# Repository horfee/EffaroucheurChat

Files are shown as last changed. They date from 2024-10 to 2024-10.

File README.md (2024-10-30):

# Effaroucheur à Chat

This project is a design of a board, based on ESP32, to control ultra sound speaker according to infrared motion sensors.

It is powered by 2 solar panels, with a LDO MP2161GJ-Z to power efficiently the device.

Used components are :
- MP2161GJ-Z
- ESP32 WROOM
- TP4056 as battery charger
- HC-SR501 for motion sensors
- << insert speaker ref here >>
- FT232RL to discuss with ESP32 for flash phase
- UMH3N to enabled RTS/DTR mechanism

Flash firmware will come later.

Current design is this :
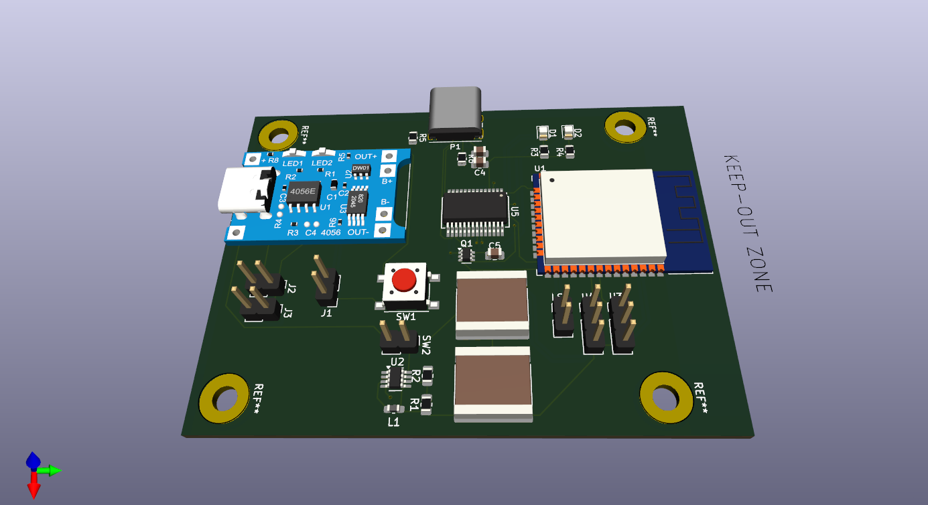
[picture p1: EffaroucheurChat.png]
The actual board


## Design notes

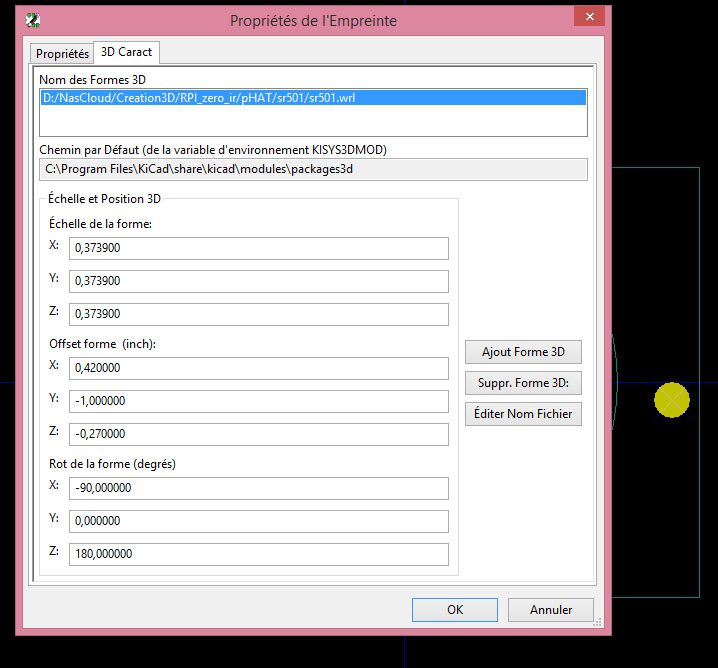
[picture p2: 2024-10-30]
HC-SR501/kidac3D1.jpg

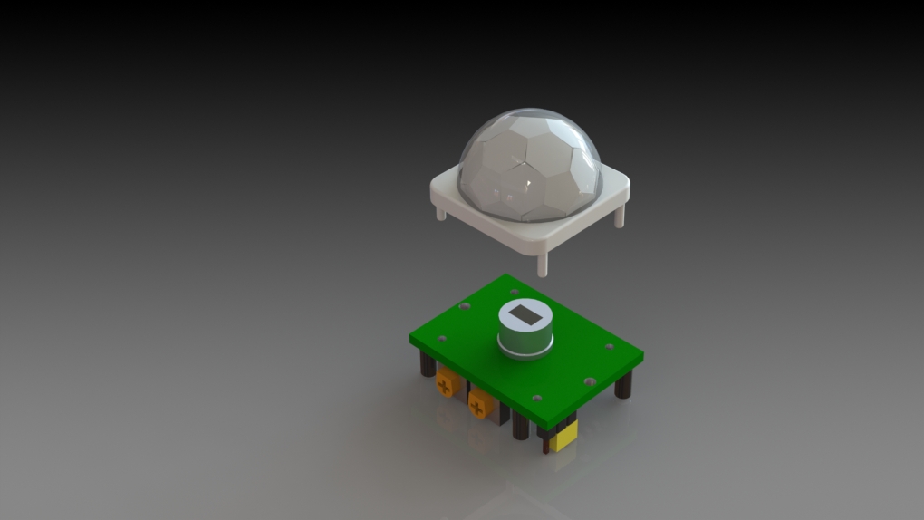
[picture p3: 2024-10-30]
HC-SR501/exploded sensor.JPG

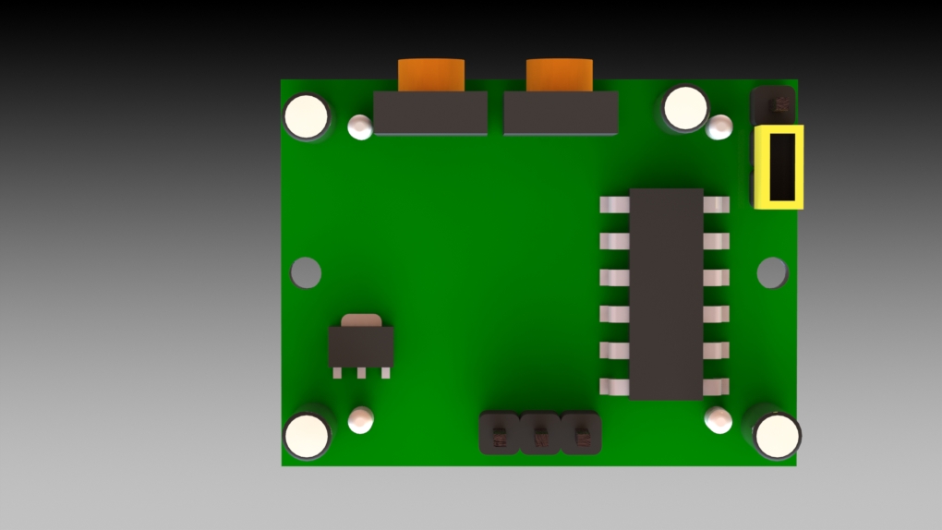
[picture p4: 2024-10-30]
HC-SR501/sensor board.JPG

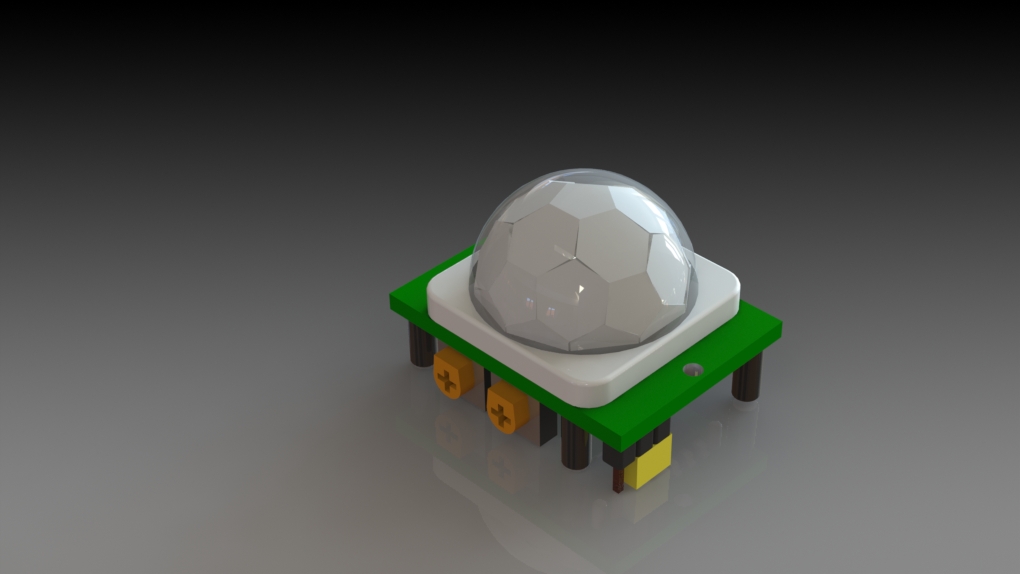
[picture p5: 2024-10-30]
HC-SR501/sensor render.JPG

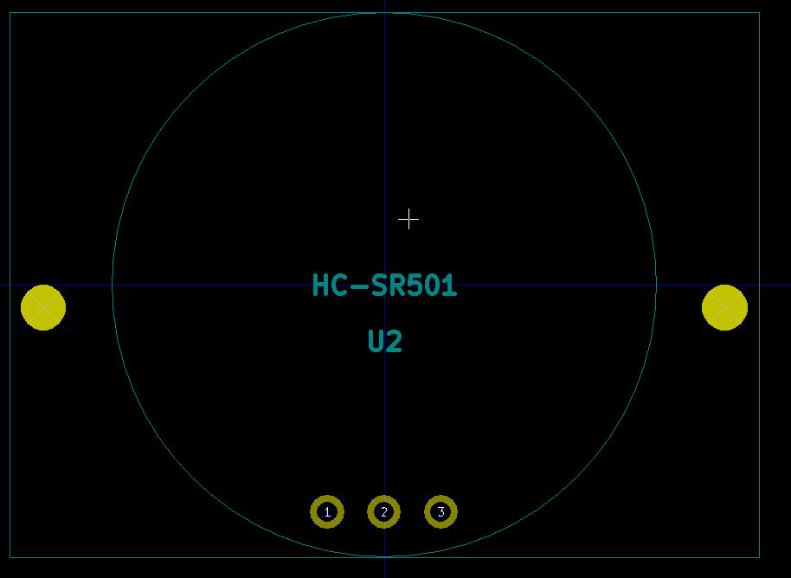
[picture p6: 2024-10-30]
HC-SR501/kidac3D2.jpg

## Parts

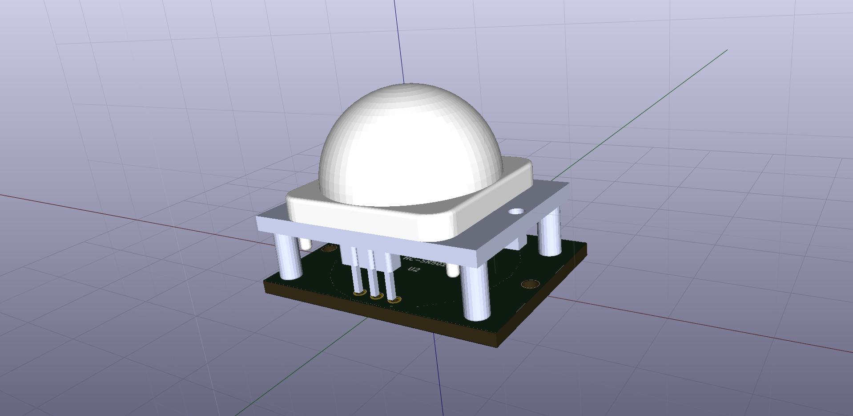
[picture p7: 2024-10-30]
HC-SR501/component.jpg

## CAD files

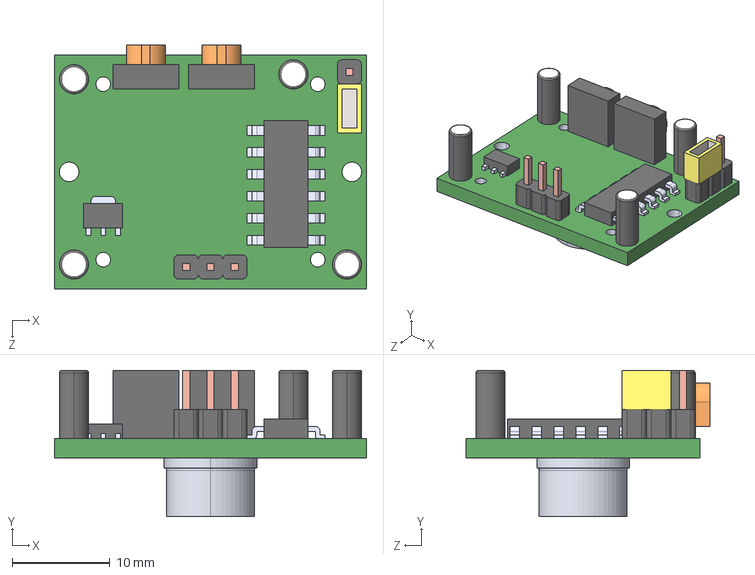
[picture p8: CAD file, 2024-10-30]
HC-SR501/sensor board.STEP
32.0 x 15.0 x 25.0 mm

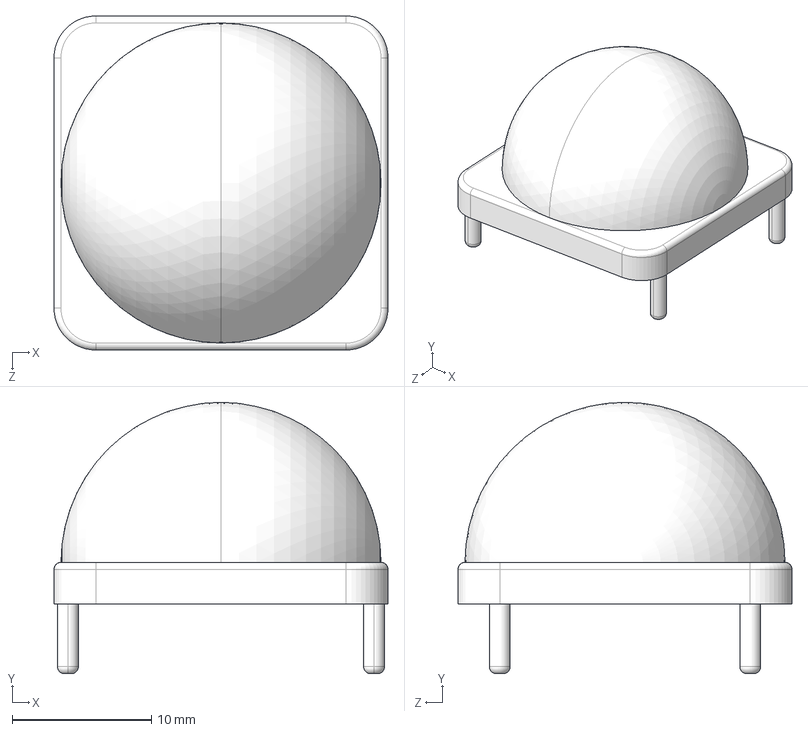
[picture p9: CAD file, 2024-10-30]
HC-SR501/lens.STEP
24.0 x 19.5 x 24.0 mm

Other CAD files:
HC-SR501/sensor.STEP
HC-SR501/lens.SLDPRT
HC-SR501/sensor.SLDASM
HC-SR501/sensor.SLDPRT

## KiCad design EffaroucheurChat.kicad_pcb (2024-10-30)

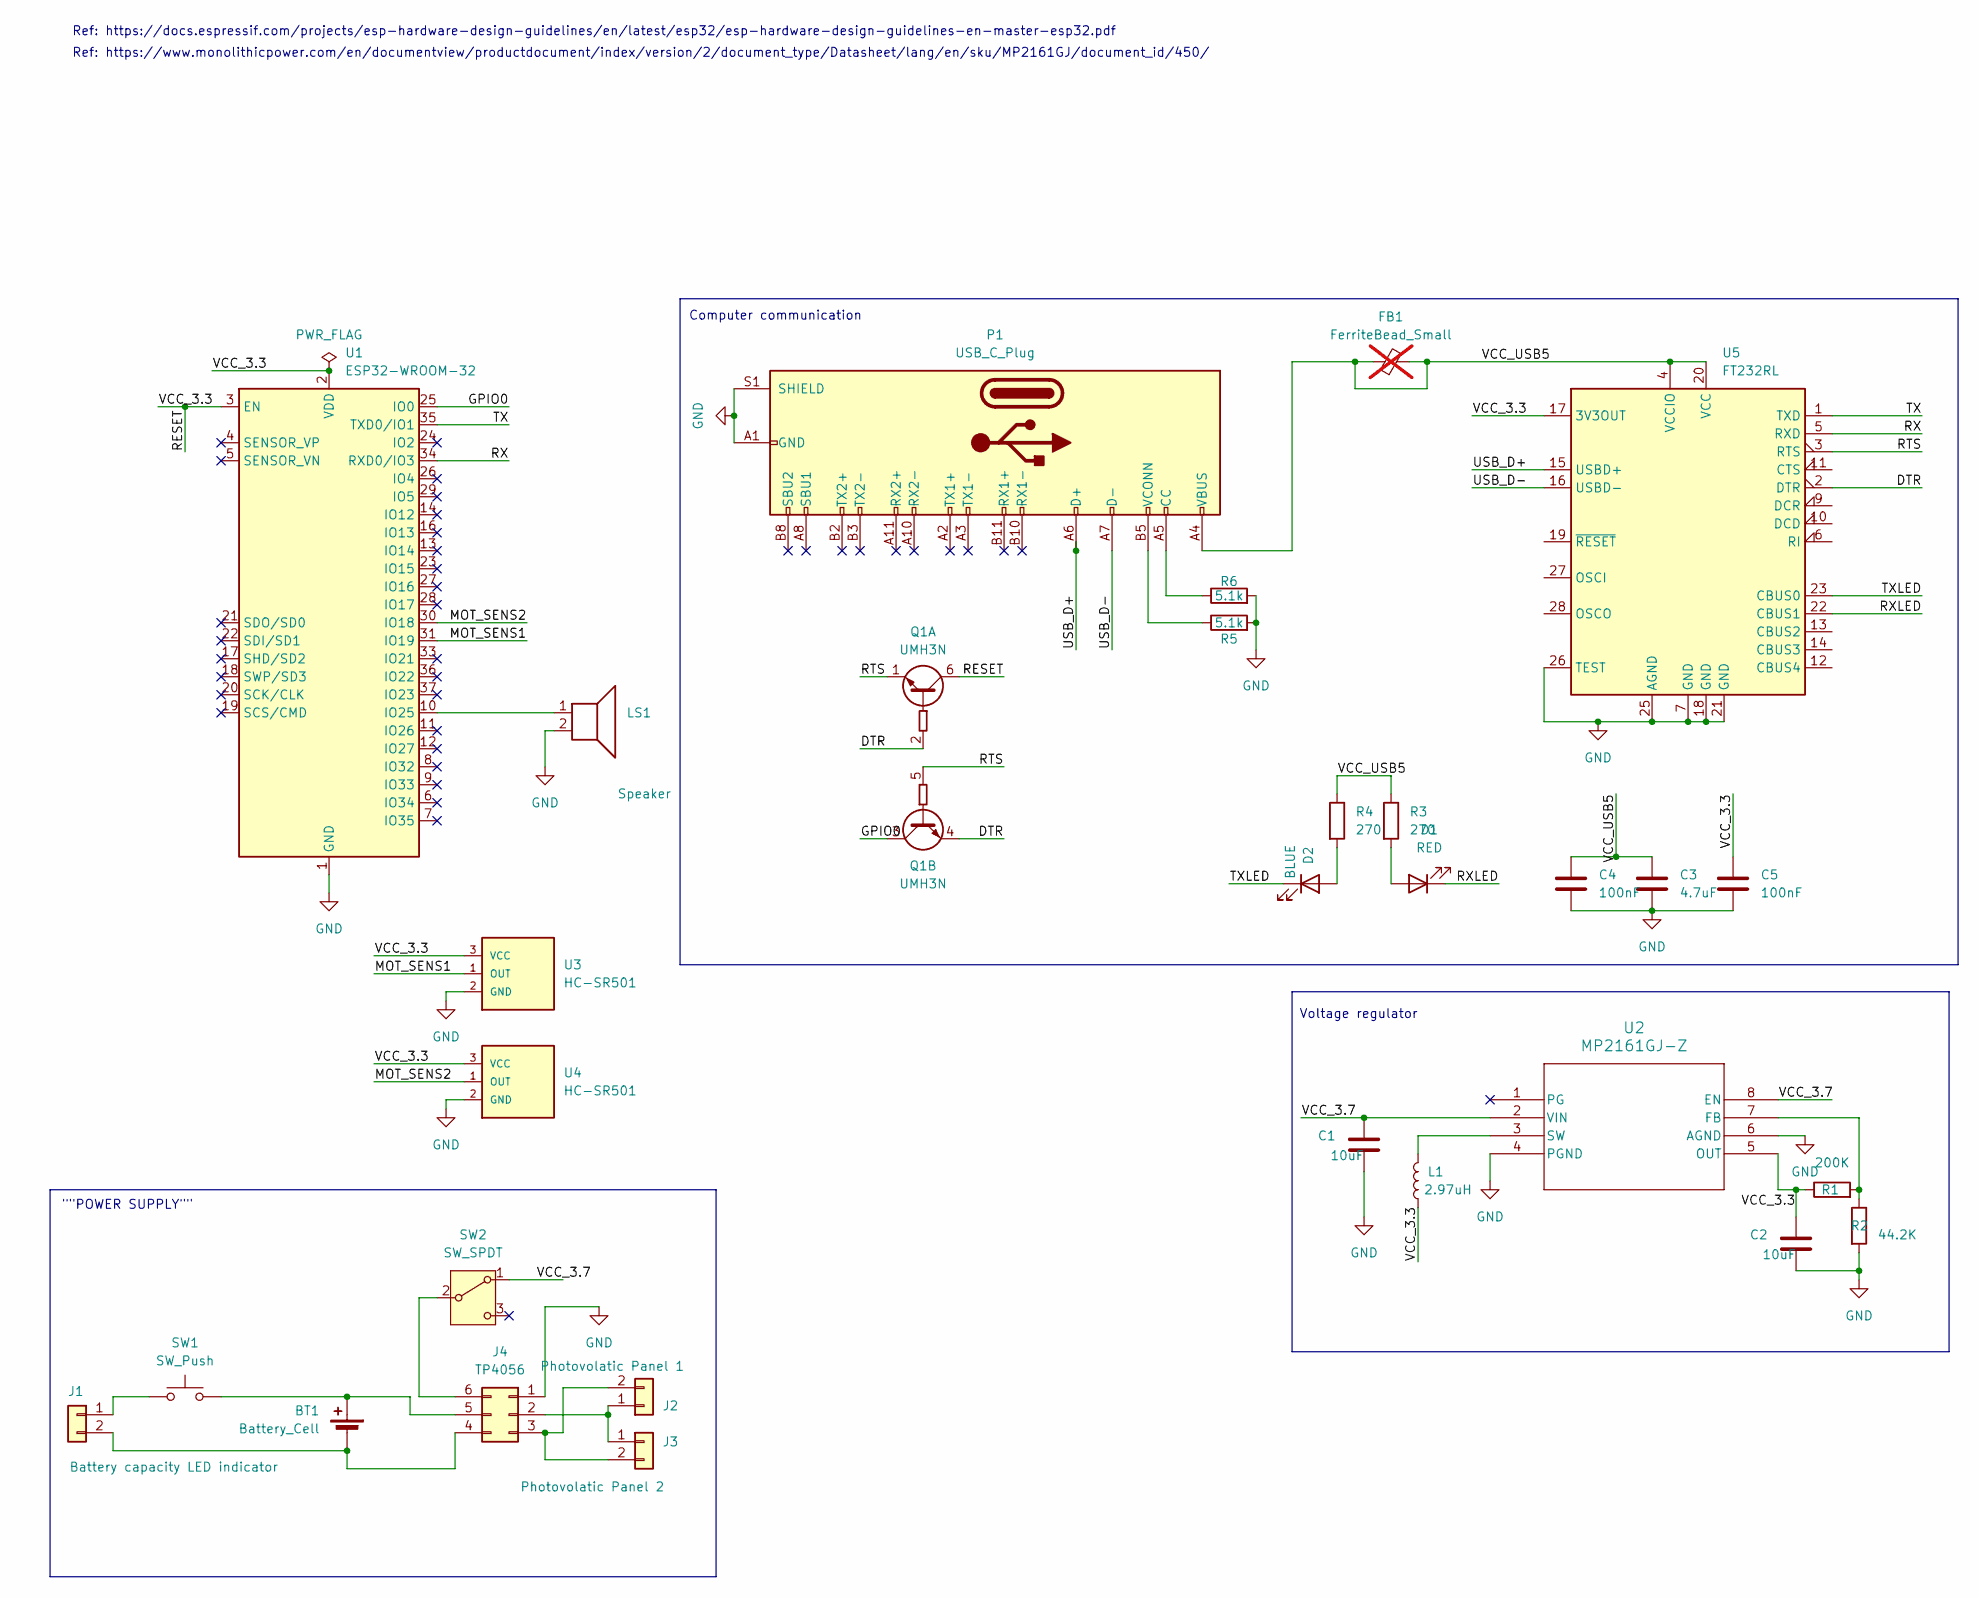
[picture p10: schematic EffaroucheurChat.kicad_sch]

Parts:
BT1: Battery_Cell
C1, C2: 10uF; C_3640_9110Metric
C3: 4.7uF; C_0805_2012Metric
C4, C5: 100nF; C_0805_2012Metric
D1: RED; LED_0805_2012Metric
D2: BLUE; LED_0805_2012Metric
FB1: FerriteBead_Small; not fitted
J1: Battery capacity LED indicator; PinHeader_1x02_P2.54mm_Vertical
J2: Photovolatic Panel 1; PinHeader_1x02_P2.54mm_Vertical
J3: Photovolatic Panel 2; PinHeader_1x02_P2.54mm_Vertical
J4: TP4056
L1: 2.97uH; L_0603_1608Metric_Pad1.05x0.95mm_HandSolder
LS1: Speaker; PinHeader_1x02_P2.54mm_Vertical
P1: USB_C_Plug; USB_C_Receptacle_GCT_USB4085
Q1: UMH3N; SOT-363_SC-70-6
R1: 200K; R_0805_2012Metric
R2: 44.2K; R_0805_2012Metric
R3, R4: 270; R_0805_2012Metric
R5, R6: 5.1k; R_0805_2012Metric
SW1: SW_Push; SW_Push_1P1T_NO_6x6mm_H9.5mm
SW2: SW_SPDT; PinHeader_1x02_P2.54mm_Vertical
U1: ESP32-WROOM-32
U2: MP2161GJ-Z; SOT-23-8_Handsoldering
U3, U4: HC-SR501; PinHeader_1x03_P2.54mm_Vertical
U5: FT232RL; SSOP-28_5.3x10.2mm_P0.65mm

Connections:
/DTR: Q1.2 (B1), Q1.4 (E2), U5.2 (DTR)
/GPIO0: Q1.3 (C2), U1.25 (IO0)
/MOT_SENS1: U1.31 (IO19), U3.1 (OUT)
/MOT_SENS2: U1.30 (IO18), U4.1 (OUT)
/RESET: C2.1, C5.1, L1.1, Q1.6 (C1), R1.1, U1.2 (VDD), U1.3 (EN), U2.5 (OUT), U3.3 (VCC), U4.3 (VCC), U5.17 (3V3OUT)
/RTS: Q1.1 (E1), Q1.5 (B2), U5.3 (RTS)
/RX: U1.34 (RXD0/IO3), U5.5 (RXD)
/RXLED: D1.1 (K), U5.22 (CBUS1)
/TX: U1.35 (TXD0/IO1), U5.1 (TXD)
/TXLED: D2.1 (K), U5.23 (CBUS0)
/USB_D+: P1.A6 (D+), U5.15 (USBD+)
/USB_D-: P1.A7 (D-), U5.16 (USBD-)
/VCC_3.7: C1.1, SW2.1 (A), U2.2 (VIN), U2.8 (EN)
/VCC_USB5: C3.1, C4.1, FB1.1, FB1.2, P1.A4 (VBUS), P1.A9 (VBUS), P1.B4 (VBUS), P1.B9 (VBUS), R3.1, R4.1, U5.4 (VCCIO), U5.20 (VCC)
GND: C1.2, C2.2, C3.2, C4.2, C5.2, J4.1, LS1.2, P1.A1 (GND), P1.A12 (GND), P1.B1 (GND), P1.B12 (GND), P1.S1 (SHIELD), R2.2, R5.2, R6.2, U1.1 (GND), U1.15 (GND), U1.38 (GND), U1.39 (GND), U2.4 (PGND), U2.6 (AGND), U3.2 (GND), U4.2 (GND), U5.7 (GND), U5.18 (GND), U5.21 (GND), U5.25 (AGND), U5.26 (TEST)
unnamed: BT1.1 (+), J4.5, SW1.2
unnamed: BT1.2 (-), J1.2, J4.4
unnamed: D1.2 (A), R3.2
unnamed: D2.2 (A), R4.2
unnamed: J1.1, SW1.1
unnamed: J2.1, J3.1, J4.2
unnamed: J2.2, J3.2, J4.3
unnamed: J4.6, SW2.2 (B)
unnamed: P1.A5 (CC), R6.1
unnamed: P1.B5 (VCONN), R5.1
unnamed: LS1.1, U1.10 (IO25)
unnamed: R1.2, R2.1, U2.7 (FB)
unnamed: L1.2, U2.3 (SW)

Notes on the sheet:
Computer communication
""POWER SUPPLY""
Voltage regulator
Ref: https://docs.espressif.com/projects/esp-hardware-design-guidelines/en/latest/esp32/esp-hardware-design-guidelines-en-master-esp32.pdf
Ref: https://www.monolithicpower.com/en/documentview/productdocument/index/version/2/document_type/Datasheet/lang/en/sku/MP2161GJ/document_id/450/

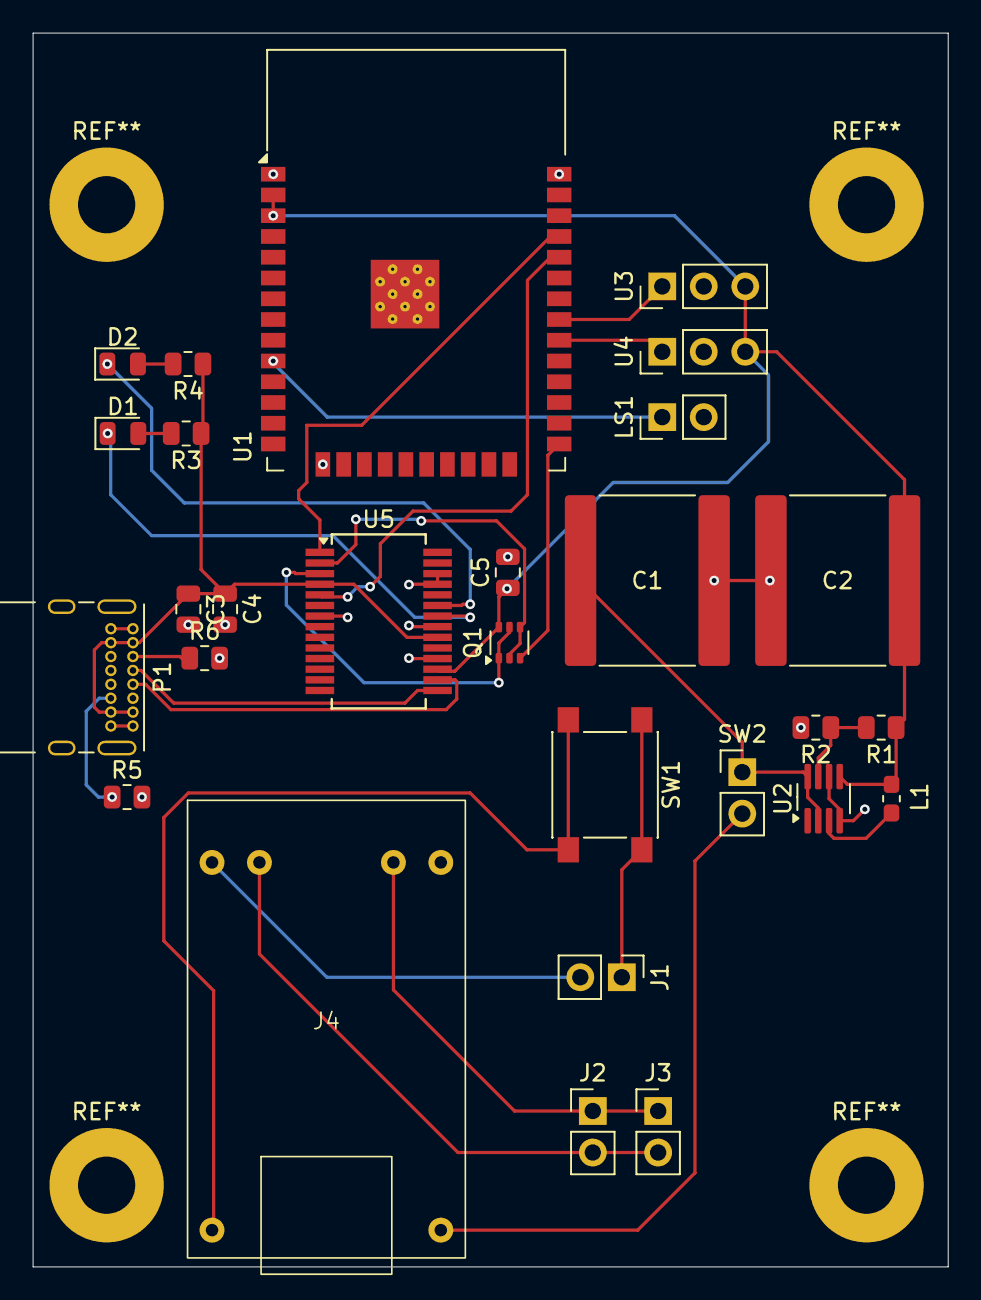
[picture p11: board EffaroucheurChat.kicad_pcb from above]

Board: 4 copper layers, 56.0 x 75.5 mm, 28 parts (0 on the bottom side), 28 nets.
